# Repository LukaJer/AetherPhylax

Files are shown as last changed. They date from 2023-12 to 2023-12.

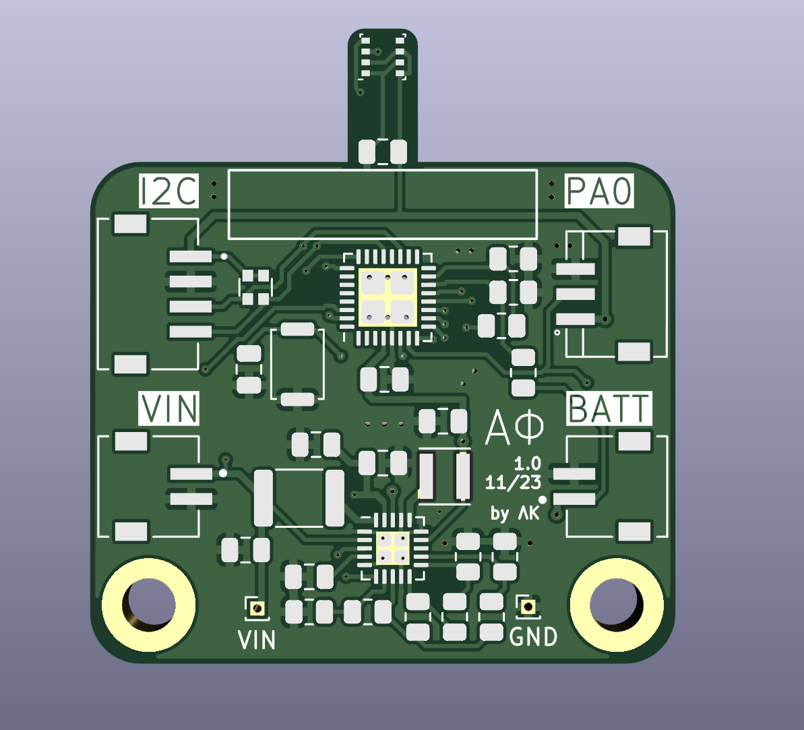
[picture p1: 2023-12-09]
Hardware/Screenshot_20231209_120351.png

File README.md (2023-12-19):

# AetherPhylax 

## Tiny Energy Harvesting Environment Monitior 


### Hardware Desctiption:  
- uC: STM32G071
- LoRa Module: RFM95
- power management: BQ25570 (<5.5V)
- I2C 
- 1 GPIO: (PA0 (int0))
- JST ZH 1.5mm connectors
- 1.27mm header for for programming and debugging (SWD+UART)
#### Detailed Description  
It's centered around a STM32G071 microcontroller and uses LoRa for efficient and longish range communication. Currently it sends to a custom Gateway which forwards the data to a MQTT server but the code can be easily adapted to use another LoRa infrastructure like The Things Network. The LoRa Module is a RFM95.  
A 18650 cell (other Li Ion batterys can be used too) is used for power  which is charged  by a TI BQ25570 which harvests energy from a solar panel. The uC can read the solar and battery voltage.  
There is 1 GPIO available (PA0 (int0)) and a I2C bus. The GPIO has a footprins for a pull-up/-down resistor or capacitor and 3V3 and GND connections next to them. JST ZH 1.5mm connectors are used and a 1.5mm pinout is present for programming and debugging (SWD+UART).

### Software Description:
The project is written in Arduino.  
Each Station has it's own name so multiple can be used on a single Gateway. 
The station wakes up in specified Intervalls (2min) and checks if any of the sensor values have changed, if so it sends the data as a JSON to the Gatway. The data is send every 10th wakeup no matter the values as a heartbeat. 
Currently
- Bosch BME280
- Sensiron SHT31
- Lacrosse TX23
- MaXIM DS18B20
- generic simple rain sensor
are implemented an can be enabled by uncommenting code.

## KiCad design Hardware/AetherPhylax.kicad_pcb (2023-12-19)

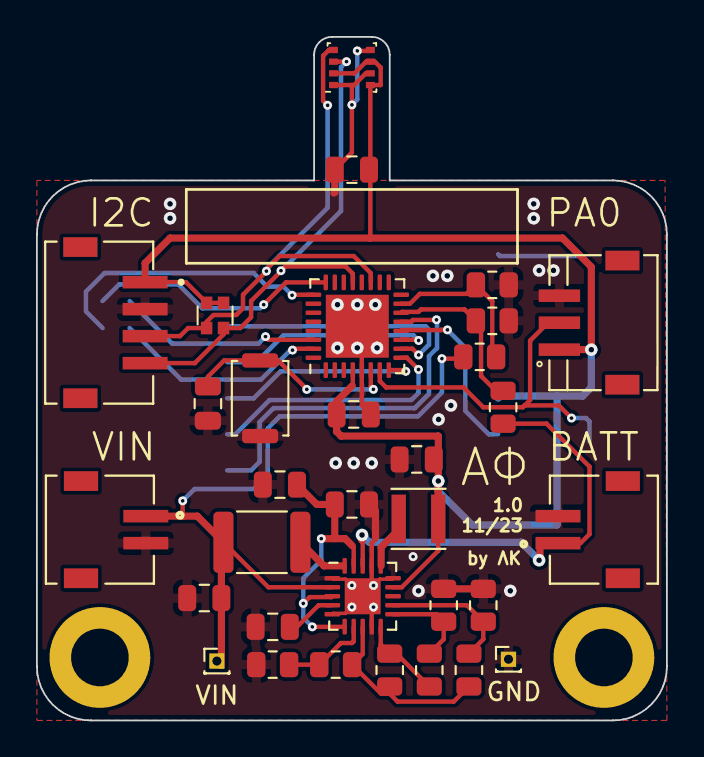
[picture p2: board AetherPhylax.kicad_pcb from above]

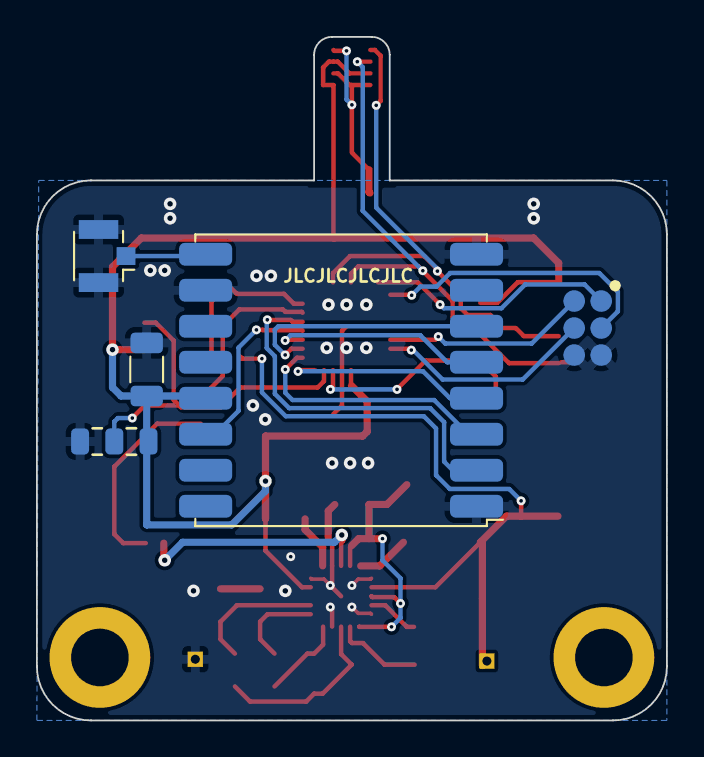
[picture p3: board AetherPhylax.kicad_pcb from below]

Board: 2 copper layers, 35.0 x 38.0 mm, 39 parts (5 on the bottom side), 30 nets.

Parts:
ANT1: Conn_Coaxial; U.FL_Hirose_U.FL-R-SMT-1_Vertical
BATT1: Conn_01x02; JST_S2B-ZR-SM4A-TF(LF)(SN)
C1, C2, C3: 0.1uF; C_0805_2012Metric
C4: 1uF; C_1206_3216Metric
CBYP1: 0.01u; C_0805_2012Metric
CIN1: 4.7u; C_0805_2012Metric
COUT1: 22u; C_0805_2012Metric
CREF1: 10n; C_0805_2012Metric
CSTOR1: 4.7u; C_0805_2012Metric
DEBUG1: Conn_02x03_Odd_Even; TestPoint_2x03_1.5mm
H1, H2: M3_Pad; MountingHole_3.2mm_M3_DIN965_Pad
I2C1: Conn_01x04; JST_S4B-ZR-SM4A-TF(LF)(SN)
J1, J2: Conn_01x01_Pin; PinHeader_1x01_P1.00mm_Vertical
JP1: Jumper_3_Open; Jumper_3_0805
L1: 22u; L_1812_4532Metric
L2: 10u; IND_LQH3NPN100MJRL
PA1: Conn_01x03; JST_S3B-ZR-SM4A-TF
R1: 0R; R_0805_2012Metric
R2: 47k; R_0805_2012Metric
R3: DNP; R_0805_2012Metric
R4: 169k; R_0805_2012Metric
RN1: R_Pack02; R_Array_Convex_2x0606
ROK1: 0.3M; R_0805_2012Metric
ROK2: 6.2M; R_0805_2012Metric
ROK3: 3.4M; R_0805_2012Metric
ROUT1: 6.34M; R_0805_2012Metric
ROUT2: 3.57M; R_0805_2012Metric
ROV1: 5.49M; R_0805_2012Metric
ROV2: 4.42M; R_0805_2012Metric
RST1: SW_Push; SW_Push_SPST_NO_Alps_SKRK
U1: QFN-20-1EP_3.5x3.5mm_P0.5mm_EP2x2mm
U2: BME280; Bosch_LGA-8_2.5x2.5mm_P0.65mm_ClockwisePinNumbering
U3: STM32G071KxU; UFQFPN-32-1EP_5x5mm_P0.5mm_EP3.5x3.5mm
U4: RFM95W-868S2; HOPERF_RFM9XW_SMD
VIN1: Conn_01x02; JST_S2B-ZR-SM4A-TF(LF)(SN)

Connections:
+3V3: C1.1, C2.1, C4.1, COUT1.1, I2C1.1, JP1.3 (B), L2.2, PA1.1, RN1.1 (R1.1), RN1.2 (R2.1), U1.14 (VOUT), U2.2 (CSB), U2.6 (VDDIO), U2.8 (VDD), U3.4 (VDD/VDDA), U4.13 (3.3V)
+BATT: BATT1.1, R2.1, U1.18 (VBAT)
/VBAT_OV: ROV1.2, ROV2.1, U1.7 (VBAT_OV)
/VOUT_SET: ROUT1.2, ROUT2.1, U1.12 (VOUT_SET)
/VSTOR: CBYP1.1, CSTOR1.1, U1.3 (VOC_SAMP), U1.6 (VOUT_EN), U1.19 (VSTOR)
ADC_Batt: R2.2, R4.1, U3.14 (PA7)
ADC_Sol: R1.2, R3.1, U3.15 (PB0)
CS: U3.11 (PA4), U4.5 (NSS)
GND: ANT1.2 (Ext), BATT1.2, C1.2, C2.2, C3.2, C4.2, CBYP1.2, CIN1.2, COUT1.2, CREF1.2, CSTOR1.2, DEBUG1.5, DEBUG1.6, I2C1.2, J2.1, JP1.1 (A), PA1.3, R3.2, R4.2, ROK3.2, ROUT2.2, ROV2.2, RST1.2, U1.1 (VSS), U1.5 (~EN), U1.9 (VSS), U1.15 (VSS), U1.17 (VSS), U1.21 (VSS), U2.1 (GND), U2.5 (SDO), U2.7 (GND), U3.5 (VSS/VSSA), U3.33 (VSS/VSSA), U4.1 (GND), U4.8 (GND), U4.10 (GND), VIN1.2
INT: U3.12 (PA5), U4.14 (DIO0)
MISO: U3.13 (PA6), U4.2 (MISO)
MOSI: U3.9 (PA2), U4.3 (MOSI)
unnamed: ANT1.1 (In), U4.9 (ANT)
unnamed: L1.2, U1.20 (LBOOST)
unnamed: L2.1, U1.16 (LBUCK)
unnamed: ROK1.2, ROK2.1, U1.10 (OK_HYST)
unnamed: ROK2.2, ROK3.1, U1.11 (OK_PROG)
unnamed: ROK1.1, ROUT1.1, ROV1.1, U1.8 (VRDIV)
unnamed: CREF1.1, U1.4 (VREF_SAMP)
unnamed: C3.1, RST1.1, U3.6 (~RST/PF2)
PA0: JP1.2 (C), PA1.2, U3.7 (PA0)
RST: U3.10 (PA3), U4.6 (RESET)
RX: DEBUG1.4, U3.31 (PB7)
SCK: U3.8 (PA1), U4.4 (SCK)
SCL: I2C1.3, RN1.3 (R2.2), U2.4 (SCK), U3.19 (PA9)
SDA: I2C1.4, RN1.4 (R1.2), U2.3 (SDI), U3.21 (PA10)
SWCLK: DEBUG1.3, U3.25 (PA14/BOOT0)
SWDIO: DEBUG1.1, U3.24 (PA13)
TX: DEBUG1.2, U3.30 (PB6)
VDD: CIN1.1, J1.1, L1.1, R1.1, U1.2 (VIN_DC), VIN1.1

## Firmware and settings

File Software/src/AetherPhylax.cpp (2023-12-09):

#define RH_ENABLE_ENCRYPTION_MODULE
#include <RH_RF95.h>
#include <Arduino.h>
#include <RHEncryptedDriver.h>
#include <Speck.h>
#include <Wire.h>
#include <ArduinoJson.h>
#include <LaCrosse_TX23.h>
#include "STM32LowPower.h"

// General Pin Definitions
#define RFM95_RST PA3
#define RFM95_CS PA4
#define RFM95_INT PA5
#define MISO PA6
#define MOSI PA2
#define SCK PA1
#define I2C_SDA PA10
#define I2C_SCL PA9

#define F_CPU 16000000

// Uncomment used Sensors:
// #define WIND
#define BME280
// #define RMTSENS
// #define SHT31
// #define RAIN

// Radiohead RF95 Driver
RH_RF95 rf95(RFM95_CS, RFM95_INT);			// Instanciate a LoRa driver
Speck myCipher;								// Instanciate a Speck block ciphering
RHEncryptedDriver myDriver(rf95, myCipher); // Instantiate the driver with those two

// Bosch BME280 Definition
#ifdef BME280
#include <Adafruit_Sensor.h>
#include <Adafruit_BME280.h>
#define SEALEVELPRESSURE_HPA (1013.25)
Adafruit_BME280 bme;
float Temp, Hum, Press;
byte BME280init_ok = 0, BME280_ok = 0;
#endif // BME280

// Sensorion SHT31 Definition
#ifdef SHT31
#include "Adafruit_SHT31.h"
Adafruit_SHT31 sht31 = Adafruit_SHT31();
float Temp1, Hum1;
#endif // SHT31

// MaXIM DS18B20 Definition
#ifdef RMTSENS
#define RemoteTempPin PA15
#include <OneWire.h>
#include <DallasTemperature.h>
OneWire oneWire(RemoteTempPin);
DallasTemperature RemoteSensor(&oneWire);
#endif // RMTSENS

// LaCrosse TX23 Definition
#ifdef WIND
#define Wind_Pin PB8
LaCrosse_TX23 anemometer = LaCrosse_TX23(Wind_Pin);
float speed, speed_old;
uint16_t dir, dir_old;
#endif // WIND

// Generic Rain Interrupt Sensor Definition
#ifdef RAIN
#define rainPin PA0 // fixed!!
volatile uint8_t rainPulses = 0;
void rainfct();
#endif // RAIN

float frequency = 868.0;																// LoRa Frequency
unsigned char encryptkey[16] = {1, 2, 3, 4, 5, 6, 7, 8, 9, 10, 11, 12, 13, 14, 15, 16}; // The very secret key
String name = "APhi0";																	// Name of the Weather Station
uint8_t HWMessageLen, nrWakeup = 0;
DynamicJsonDocument payload(512);			   // JSON Definition (might be shortened)
int SendInterval_LP = 600, SendInterval = 120; //  (Low Power) Send Intervall in Seconds
int ValChng = 0;							   // Tracks if values have changed
float VBatt, VSol;

void setup()
{
	// Set UART Pins
	Serial.setRx(PB7);
	Serial.setTx(PB6);
	Serial.begin(9600);

	payload["Name"] = name;
	Serial.println("AetherPhylax Client: " + name);
	delay(100);

	// Set I2C Pins
	Wire.setSDA(I2C_SDA);
	Wire.setSCL(I2C_SCL);
	Wire.begin();

// Sensor Initalisation
#ifdef BME280
	unsigned status;
	status = bme.begin(0x76);
	if (!status)
	{
		Serial.println("Could not find a valid BME280 sensor, check wiring, address, sensor ID!");
		Serial.print("SensorID was: 0x");
		Serial.println(bme.sensorID(), 16);
		Serial.print("        ID of 0xFF probably means a bad address, a BMP 180 or BMP 085\n");
		Serial.print("   ID of 0x56-0x58 represents a BMP 280,\n");
		Serial.print("        ID of 0x60 represents a BME 280.\n");
		Serial.print("        ID of 0x61 represents a BME 680.\n");
				BME280init_ok = 0;
		BME280_ok = 0;
	}
	else
	{
		BME280init_ok = 1;
		BME280_ok = 1;
	}

#endif // BME280

#ifdef SHT31
	if (!sht31.begin(0x44))
	{ // Set to 0x45 for alternate i2c addr
		Serial.println("Couldn't find SHT31");
		while (1)
			delay(1);
	}
#endif // SHT31

#ifdef RMTSENS
	RemoteSensor.begin();
#endif // RMTSENS

	// Set SPI Pins
	SPI.setMISO(MISO);
	SPI.setMOSI(MOSI);
	SPI.setSCLK(SCK);
	delay(10);

	// LoRa Initalisation
	if (!rf95.init())
	{
		Serial.println("LoRa init failed");
		while (1) // Halt Startup if RF95 not found
			delay(1);
	}
	rf95.setFrequency(frequency);
	rf95.setTxPower(13);
	myCipher.setKey(encryptkey, sizeof(encryptkey));

	LowPower.begin();
// Enable Rain Interrupt
#ifdef RAIN
	pinMode(rainPin, INPUT_FLOATING);
	LowPower.attachInterruptWakeup(rainPin, rainfct, RISING, DEEP_SLEEP_MODE);
#endif // RAIN

	Serial.println("Setup completed");
	delay(1000);
}

void loop()
{

	float buffer = 0;

	delay(50);
	Serial.print("Wake-Up Nr: ");
	Serial.println(nrWakeup);
	// Keeping Track of #Wakeups
	nrWakeup++;
	// Data gets send every 10th wake-up independent wether data has changed: Heartbeat
	if (!(nrWakeup % 10))
	{
		ValChng = 1;
		if (!BME280_ok)
			LowPower.shutdown(100); // Restart
	}
	delay(50);

#ifdef RAIN
	Serial.print("Rainpulse: ");
	Serial.println(rainPulses);
#endif

// Read Wind Data
#ifdef WIND
	if (anemometer.read(speed, dir))
	{
		Serial.println("Wind found");
		/* Wind Data gets only sent if speed is greater 0 and
		Speedchange > 0.5 or
		ValChng = 1 or
		Direction Change > 0.5
		*/
		if (abs(speed_old - speed) > 0.5 || ValChng || ((abs(dir_old - dir) > 0.5) && speed > 0))
		{
			ValChng = 1;
			payload["Speed"] = speed;
			speed_old = speed;
			payload["Dir"] = dir * 22.5;
			dir_old = dir;
		}
	}
#endif // WIND

// Read BME280 Data
#ifdef BME280
	if (BME280init_ok)
	{
		if (bme.takeForcedMeasurement())
		{
			BME280_ok = 1;
			/* BEM280 Data gets only sent if
			Temperaturechange > 0.5°C or
			Humiditychange > 5%
			*/
			buffer = bme.readTemperature() / 1.0;
			if (abs(Temp - buffer) > 0.5 || ValChng)
			{
				ValChng = 1;
				payload["Temp"] = buffer;
				Temp = buffer;
			}
			buffer = roundf(bme.readHumidity() * 100) / 100;
			if (abs(Hum - buffer) > 5 || ValChng)
			{
				ValChng = 1;
				payload["Hum"] = buffer;
				Hum = buffer;
			}

			buffer = roundf(bme.readPressure()) / 100;
			if (abs(Press - buffer) > 0.5 || ValChng)
			{
				ValChng = 1;
				payload["Press"] = buffer;
				Press = buffer;
			}
		}
		else
			BME280_ok = 0;
	}
#endif // BME280

// Read SHT 31 Data
#ifdef SHT31
	/* SHT31 Data gets only sent if
	Temperaturechange > 0.5°C or
	Humiditychange > 5%
	*/
	buffer = sht31.readTemperature();
	if (abs(Temp1 - buffer) > 0.5 || ValChng)
	{
		ValChng = 1;
		payload["Temp1"] = buffer;
		Temp1 = buffer;
	}

	buffer = sht31.readHumidity();
	if (abs(Hum1 - buffer) > 5 || ValChng)
	{
		ValChng = 1;
		payload["Hum1"] = buffer;
		Hum1 = buffer;
	}
#endif // SHT31

// Read Remote Sensor Data
#ifdef RMTSENS
	float RemoteTemp(NAN);
	RemoteSensor.requestTemperatures();
	RemoteTemp = RemoteSensor.getTempCByIndex(0);
	if (RemoteTemp != -127)
	{
		payload["RmtTmp"] = RemoteTemp;
	}
#endif // RMTSENS

#ifdef RAIN
	payload["RainC"] = rainPulses;
#endif // RAIN

	if (!ValChng)
	{
		// Don't send anything if no new Data or not a 10th wakeup
		Serial.println("No new Data, back to zzzz");
		delay(50);

		LowPower.deepSleep(SendInterval * 1000);
	}
	else
	{
#ifdef RAIN
		rainPulses = 0; // Reset RainPulses
#endif
		// Read Battery and Solar Voltages (8bit)
		VBatt = analogRead(PA7) * 4.3 / 1024;
		VSol = analogRead(PB0) * 10.9 / 1024;
		payload["VBatt"] = trunc(VBatt * 100) / 100;
		if (floor(VSol) > 0)
		{
			payload["VSol"] = trunc(VSol * 100) / 100;
		}

		size_t len = 32;
		char message[256]; // SerializedJSON, replace with len?
		len = payload.memoryUsage();
		Serial.println(len);
		serializeJson(payload, message); // Create String (Char Array) from JSON
		uint8_t data[len + 1];			 // RFM95 input

		for (uint8_t i = 0; i <= len; i++) // Copy and Typecast Data from JSONString to uint8_t Array
		{
			data[i] = (uint8_t)message[i];
		}
		data[len + 1] = '\0';
		myDriver.send(data,  (uint8_t)sizeof(data)); // Send out ID + Sensor data to LoRa gateway
		Serial.print("Sent: ");
		delay(50);
		Serial.println((char *)&data);
		delay(50);
		rf95.sleep(); // Put RF95 to sleep
		ValChng = 0;
		delay(100);
		// Check if Battery is above 3V, if not use LowPower Intervall for Wakups, current not used!
		if (VBatt > 3.0)
			LowPower.deepSleep(SendInterval * 1000);
		else
		{
			LowPower.deepSleep(SendInterval_LP * 1000);
			ValChng = 1;
		}
	}
}

/*
Rain Interrupt triggers this function
Increment Number of Rain Pulses an go back to Sleep
*/
#ifdef RAIN
void rainfct()
{
	rainPulses++;
	delay(50);
	LowPower.deepSleep();
}
#endif // RAIN
